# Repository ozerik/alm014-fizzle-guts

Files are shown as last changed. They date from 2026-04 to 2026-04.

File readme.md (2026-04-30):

# M4TM FZilter

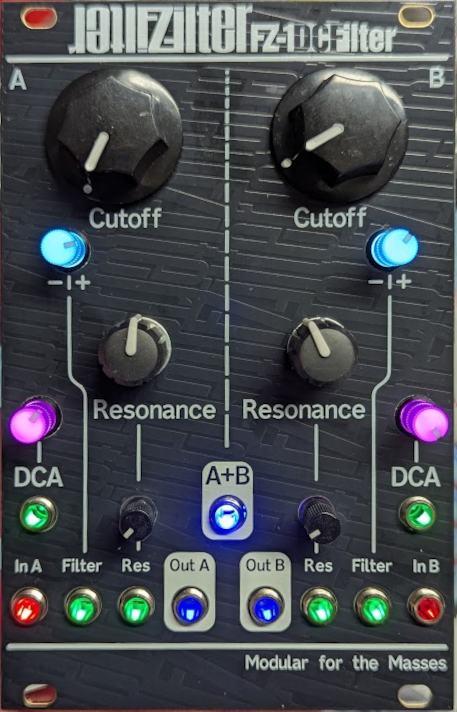
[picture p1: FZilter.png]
picture of my FZilter module


## Introduction

Here's my take on the excellent Fizzle Guts module by ALM/BusyCircuits. It rules.

I've redrawn the schematic, altering a few resistor values and adding ground-reference resistors after the capacitors on the input sides 
(how did input bias not saturate those caps? Are we relying on DC leakage in electrolytics?), I added a 2nd 5V voltage regulator for the microcontroller, lifted the
ground on the microcontroller side, and OF COURSE I added LEDs everywhere, inclduing the ones under the clear-shafted potentiometers. I haven't compared the
character of my version against the original, so who knows if there's any improvement. Probably not, but hey, fun project!

Back in the '80s, Casio released the FV-1 keyboard with four of the MB87186 chips inside. And that's the only place you can get them. The FV-1 and the FV-1M keyboard.
If you have one of these kicking around with a broken logic board or keybed or output whatever, you do have four of these chips that are probably okay. One of the chips I
built up into a module looked pretty rough, water? stains and corroded bent pins, still worked.

For more information on the MB87186 (and from what much of the code
was based on) see http://www.buchty.net/casio/dcf.html

See, this is a dual DCF and DCA. "D" standing for digital, of course, so digitally-controlled filter and amp. ALM developed the code to turn voltages into digital signals, and figured out (based on excellent work linked above) how to get that datastream into the chip so it knows what to do with it. Great work, everybody, hats off.

## Building and flashing the firmware

The most frightning part of this project was getting the code onto the microprocessor. The flash.sh shell script will work with the correct hardware,
but I don't have a Macintosh computer, or a USBTiny programmer. I just have a HP laptop and a bunch of Arduinos flashed with the "Arduino-as-ISP" firmware because I keep
losing them and making new ones. AND I'm not super comofortable with avrdude... so I'll include the .hex file over in the firmware folder and a bit of explanation of the
commands. It may be possible to brick the ATMega644 processor by setting fuses, at least something like that may have happened with one of mine.

> To use the original shell script...
>
> You'll need a basic 'usbtiny' AVR programmer.
>
> You'll need to install avr-gcc and avrdude.
>  
>   /(On mac using brew..)/
>   #+BEGIN_SRC
>   brew tap osx-cross/avr
>   brew install avr-gcc
>   brew install avrdude
>
>   #+END_SRC
>  Type 'make' in the firmare/ directory to compile the source code and
>
> then run './flash.sh' (with your programmer connected) to program the Fizzle.

Okay so here's what worked for me:

I followed the *arduous* steps over [here, which goes through how to create an AVR toolchain](https://tinusaur.com/guides/avr-gcc-toolchain/) and that
was complicated and weird, and the script in `flash.sh` wouldn't work. Mostly because avrdude changed the nanme of programmers, and who knows what else. Anyway,
as of April 2026, here's the command line I used to flash the ATMega644p chip:

`avrdude -V -p atmega644p -c avrisp -P COM5 -b 19200 -F -e -U hfuse:w:0xD8:m -U lfuse:w:0xFF:m -U efuse:w:0x04:m -U flash:w:"PATH TO fz1.hex FILE":a`

`-p atmega644p` means you're programming this particular chip

`-c avrisp` means you're using an Arduion-as-ISP programmer, which are [easy to build](https://docs.arduino.cc/built-in-examples/arduino-isp/ArduinoISP/) with an Arduino Nano

`-P COM5` referrs to which port you're using. Figure this out by looking at your Device Manager, under Ports (COM & LPT) and find the USB-SERIAL CH340 one (at least that's
what it'll be if you're using a cheap Nano clone)

`-b 19200` sets the BAUD rate, probably fine, don't even need it?

The `hfuse` and whatnot, those are fuses that tell the microprocessor which clock to use. The ATMega644 can clock itself, but for this project it must be clocked from the external 20MHz crystal. This might be how I bricked one of my modules, by trying to set fuses and messing an important one up.

The last important part of that command line is what file to flash. You'll find an fz1.hex file elsewhere in this repo, so download it somewhere and delete "PATH TO fz1.hex FILE" and replace it with "C:/Users/NicCage/Downloads/fz1.hex" (what's up Nic? cool movies) or whatever.

Then, plug your Arduino-as-ISP thingie into the header on the module, minding that you get the pins right, plug the Arduino into 
a USB port, open a command prompt window (bash shell if you've been following directions), paste that code into the command line, hit enter, and say "no" when it asks you if you want to re-set the fuse that was just set. Somebody smarter than me can fix whatever's causing that error.

SO anyway, this procedure worked for me, and I've got a functioning FZilter module in my possession.

## License

Code: MIT license.

Hardware: cc-by-sa-3.0

## Guidelines for derivative works

*ALM is a registered trademark.*

The name "ALM" should not be used on any of the derivative works you create from these files.

We kindly ask to do not name any derivatives 'FIZZLE GUTS' but give it a new name.

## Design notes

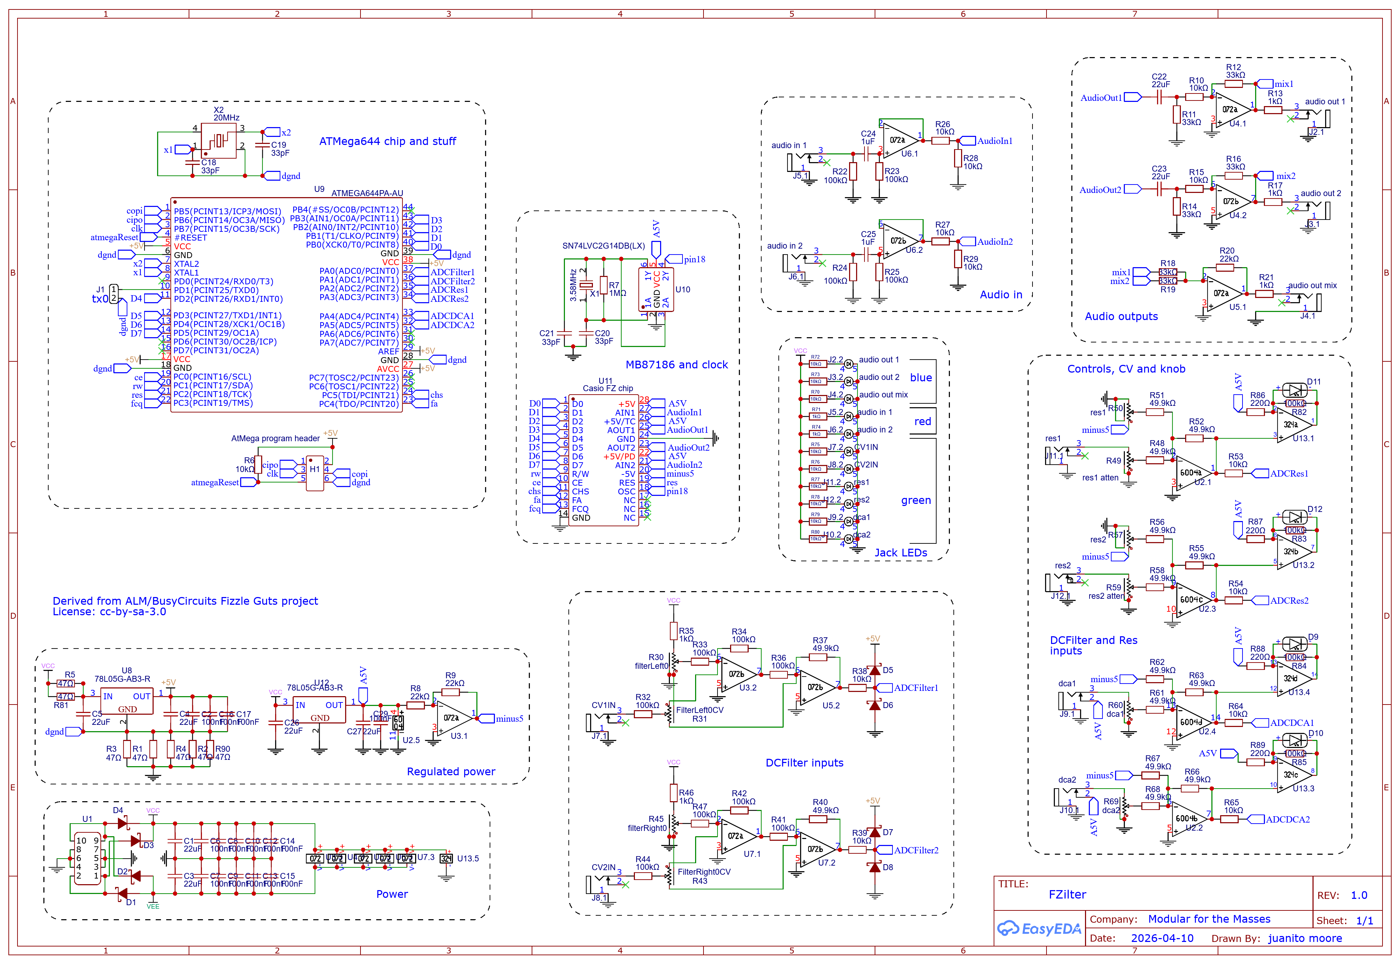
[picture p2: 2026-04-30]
hardware/M4TM_Schematics/FZilter_schematic.png

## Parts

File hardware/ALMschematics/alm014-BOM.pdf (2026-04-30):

### FZ-FILTER-REV003 Passives + IC’s BOM

Qty | Parts | Value | Device | Package | Description | MF
1 | R38 | 1M | RESISTOR0603 | R0603
14 | R1, R3, R7, R10, R12, R14, R22, R32, R33, R34, R36, R46, R9, R16 | 100K | RESISTOR0603 | R0603
15 | R15, R17, R18, R19, R20, R23, R25, R27, R30, R35, R53, R39, R11, R29, R31 | 49.9k | RESISTOR0603 | R0603
4 | R6, R48, R50, R51 | 33K | RESISTOR0603 | R0603
12 | R2, R4, R5, R21, R28, R42, R45, R47, R40, R41, R43, R44 | 10K | RESISTOR0603 | R0603
3 | R8, R13, R49 | 1K | RESISTOR0603 | R0603
2 | R26, R37 | 2.2K | RESISTOR0603 | R0603
13 | C3, C7, C8, C13, C14, C15, C17, C18, C22, C28, C29, C31, C41 | 100n | CAPACITOR0603 | C0603
4 | C11, C16, C23, C24 | 10n | CAPACITOR0603 | C0603
2 | C21, C9 | 1n | CAPACITOR0603 | C0603
2 | C6, C27 | 47pf | CAPACITOR0603 | C0603
2 | C19, C20 | 20pf | CAPACITOR0603 | C0603
5 | C1, C2, C5, C12, C26 | 10uf / 25V | CPOL-EUB | PANASONIC_B | POLARIZED CAPACITOR, European symbol | Panasonic EEEHA1E100WR (or equiv)
2 | C4, C25 | 1uf / 25V | CPOL-EUB | PANASONIC_B | POLARIZED CAPACITOR, European symbol | Panasonic EEE1HA010SR (or equiv)
2 | D3, D13 | BAT54S | BAT54S | SOT23 | Schottky Diodes | BAT45S
2 | D1, D2 | RS 301-906 | DIODESMB | SMB-DIODE | Diode | Vishay VS-MBRS130LTRPBF (or similar)
1 | QF1 | 3.58Mhz | | | 3.58Mhz Resonator | Murata CSTLS3M58G56-B0
5 | IC1, IC2, IC5, IC7, IC8 | TL072D | TL072D | SO08 | OP AMP | TL072
1 | IC3 | MCP6004 | MCP6004 | SO14 | OP AMP | MCP6004
1 | IC6 | ATMEGA644A | ATMEGA644A | TQFP44 | MCU | Mouser 556-ATMEGA644A-AU
1 | U1 | SN74LVC2G14DBV | SN74LVC2G14DBV | SOT23-6 | DUAL SCHMITT-TRIGGER INVERTER | Mouser 595-SN74LVC2G14DBVR
1 | U3 | 7805 | VREG-7805-DPAK2 | VREG-7805-DPAK2 | | Mouser L7805CD2T-TR
1 | Y2 | 8M10AHC49T | 8M10AHC49T | HC49U | 20Mhz Crystal | Mouser 420-200-20-5PX

All caps at least 16v. All resistors 1% at least 0.1 watt

1

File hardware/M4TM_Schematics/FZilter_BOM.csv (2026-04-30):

ID | Name | Designator | Footprint | Quantity | Manufacturer Part | Manufacturer | Supplier | Supplier Part
1 | 22uF | C1,C3,C4,C5,C22,C23,C26,C27 | C0805 | 8 | CL21A226MAQNNNE | SAMSUNG(三星) | LCSC | C45783
2 | 100nF | C2,C6,C7,C8,C9,C10,C11,C12,C13,C14,C15,C16,C17,C29 | C0603 | 14 | CC0603KRX7R9BB104 | YAGEO(国巨) | LCSC | C14663
3 | 33pF | C18,C19,C20,C21 | C0402 | 4 | 0402CG330J500NT | FH(风华) | LCSC | C1562
4 | 1uF | C24,C25 | C0805 | 2 | CL21B105KBFNNNE | SAMSUNG(三星) | LCSC | C28323
5 | B5819W_C8598 | D1,D2,D3,D4,D5,D6,D7,D8 | SOD-123_L2.7-W1.6-LS3.7-RD-1 | 8 | B5819W | CJ | LCSC | C8598
6 | 1x2_2.54mm_pin_header_Juanito | J1 | HDR-M-2.54_1X2 JUANITO | 1
7 | 47Ω | R1,R2,R3,R4,R5,R81,R90 | R0603 | 7 | 0603WAF470JT5E | UNI-ROYAL(厚声) | LCSC | C23182
8 | 10kΩ | R6,R10,R15,R26,R27,R28,R29,R38,R39,R53,R54,R64,R65,R70,R72,R73,R75,R76,R77,R78,R79,R80 | R0603 | 22 | 0603WAF1002T5E | UNI-ROYAL(厚声) | LCSC | C25804
9 | 1MΩ | R7 | R0603 | 1 | 0603WAF1004T5E | UNI-ROYAL(厚声) | LCSC | C22935
10 | 22kΩ | R8,R9,R20 | R0603 | 3 | 0603WAF2202T5E | UNI-ROYAL(厚声) | LCSC | C31850
11 | 33kΩ | R11,R12,R14,R16,R18,R19 | R0603 | 6 | 0603WAF3302T5E | UNI-ROYAL(厚声) | LCSC | C4216
12 | 1kΩ | R13,R17,R21,R35,R46,R71,R74 | R0603 | 7 | 0603WAF1001T5E | UNI-ROYAL(厚声) | LCSC | C21190
13 | 100kΩ | R22,R23,R24,R25,R32,R33,R34,R36,R41,R42,R44,R47,R82,R83,R84,R85 | R0603 | 16 | 0603WAF1003T5E | UNI-ROYAL(厚声) | LCSC | C25803
14 | 49.9kΩ | R37,R40,R48,R51,R52,R55,R56,R58,R61,R62,R63,R66,R67,R68 | R0603 | 14 | 0603WAF4992T5E | UNI-ROYAL(厚声) | LCSC | C23184
15 | 220Ω | R86,R87,R88,R89 | R0603 | 4 | 0603WAF2200T5E | UNI-ROYAL(厚声) | LCSC | C22962
16 | 78L05G-AB3-R | U8,U12 | SOT-89-3_L4.5-W2.5-P1.50-LS4.2-BR | 2 | 78L05G-AB3-R | UTC(友顺) | LCSC | C71136
17 | ATMEGA644PA-AU | U9 | TQFP-44_L10.0-W10.0-P0.80-LS12.0-BL | 1 | ATMEGA644PA-AU | MICROCHIP(美国微芯) | LCSC | C38349
18 | SN74LVC2G14DB(LX) | U10 | SOT-23-6_L2.9-W1.6-P0.95-LS2.9-BL | 1 | SN74LVC2G14DB(LX) | LX(灵星芯微) | LCSC | C22469937
19 | 3.58MHz | X1 | HC-49S_L11.4-W4.8-LS13.0 | 1 | SWXJHBCVH0-3.580000 | Starwave(思大) | LCSC | C22464956
20 | 20MHz | X2 | CRYSTAL-SMD_4P-L3.2-W2.5-BL | 1 | TAXM20M4RHBDDT2T | YJX(雅晶鑫) | LCSC | C2880033
21 | 6004 jm | U2 | TSSOP-14PLUS3D | 1 | TPMCP6004T-E/ST | TECH PUBLIC | LCSC | C42370557
22 | TL072CDT JUANITO | U3,U4,U5,U6,U7 | SOIC-8_L5.0-W4.0-P1.27-LS6.0-BL | 5 | TL072CDT | STMicroelectronics | LCSC | C6961
23 | LM324 Juanito 0 | U13 | SOIC-14_L8.7-W3.9-P1.27-LS6.0-TL | 1 | LM324DT | ST(意法半导体) | LCSC | C71035

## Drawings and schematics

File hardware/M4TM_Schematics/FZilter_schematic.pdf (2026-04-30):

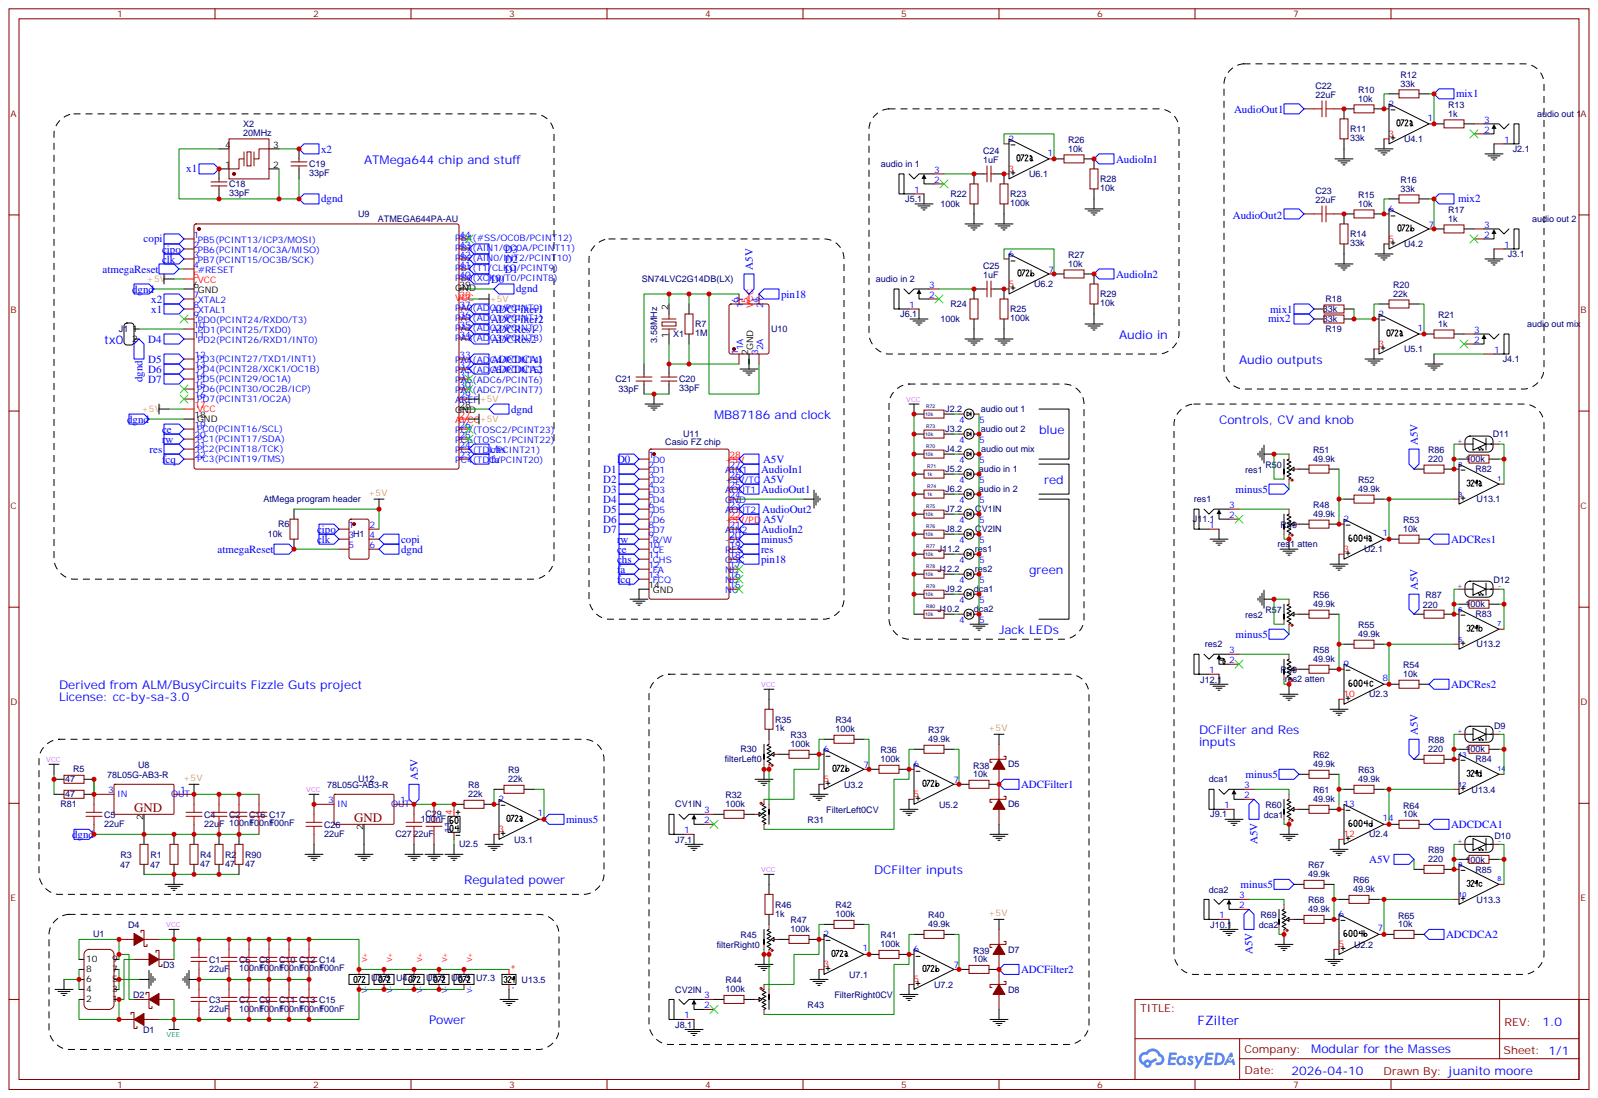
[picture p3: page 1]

mix1
mix2
Company: Modular for the Masses A⁵V A⁵V A⁵V

Controls, CV and knob

Derived from ALM/BusyCircuits Fizzle Guts project
License: cc-by-sa-3.0

Drawn By: juanito moore

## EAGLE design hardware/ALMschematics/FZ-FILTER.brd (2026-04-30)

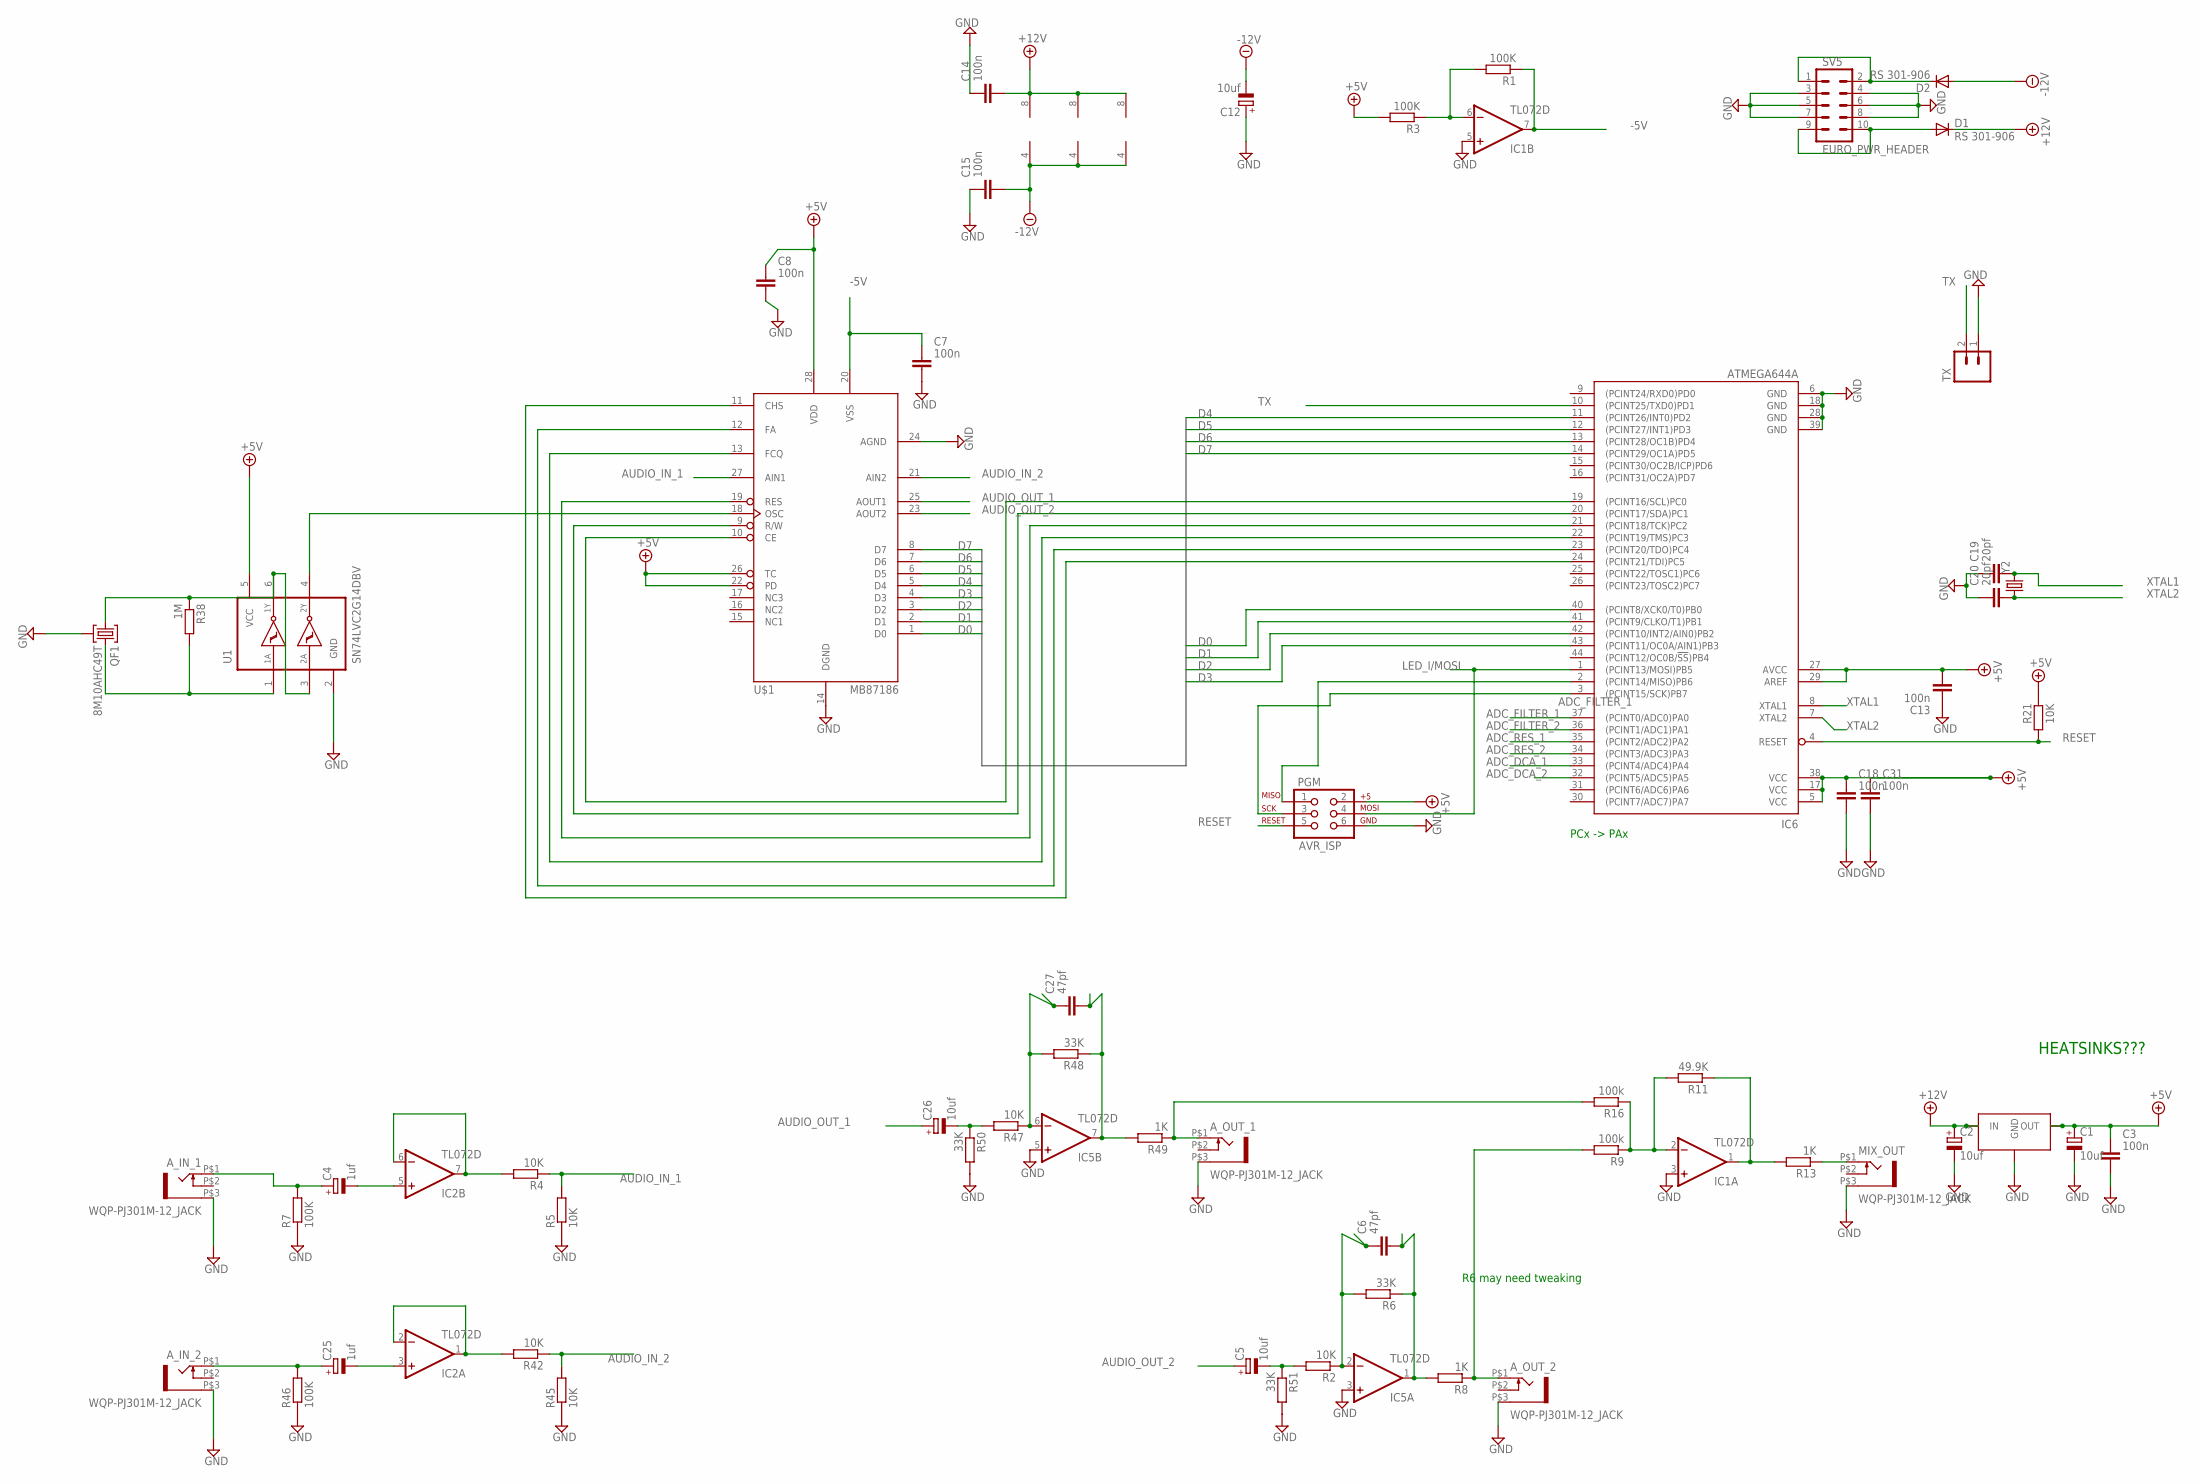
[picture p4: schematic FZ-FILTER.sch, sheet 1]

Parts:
A_IN_1, A_IN_2: WQP-PJ301M-12_JACK
A_OUT_1, A_OUT_2: WQP-PJ301M-12_JACK
C1, C2, C5, C12, C26: 10uf; PANASONIC_B
C3, C7, C8, C13, C14, C15, C18, C31: 100n; C0603
C4, C25: 1uf; PANASONIC_B
C6, C27: 47pf; C0603
C19, C20: 20pf; C0603
D1, D2: RS 301-906; SMB-DIODE
IC1, IC2, IC5: TL072D; SO08
IC6: ATMEGA644A; TQFP44
MIX_OUT: WQP-PJ301M-12_JACK
PGM: AVR_ISP; 2X3
QF1: 8M10AHC49T; HC49U
R1, R3, R7, R46: 100K; R0603
R2, R4, R5, R21, R42, R45, R47: 10K; R0603
R6, R48, R50, R51: 33K; R0603
R8, R13, R49: 1K; R0603
R9, R16: 100k; R0603
R11: 49.9K; R0603
R38: 1M; R0603
SV5: EURO_PWR_HEADER
TX: M02PTH; 1X02
U1: SN74LVC2G14DBV; SOT23-6
U3: 7805; VREG-7805-DPAK2
U$1: MB87186; DIP28
Y2: CRYSTALSMD; HC49UP

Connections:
+5V: C1.+, C3.1, C8.1, C13.2, C18.1, C31.1, IC6.5 (VCC), IC6.17 (VCC), IC6.27 (AVCC), IC6.29 (AREF), IC6.38 (VCC), PGM.2, R3.2, R21.2, U1.5 (VCC), U3.VOUT (OUT), U$1.22 (PD), U$1.26 (TC), U$1.28 (VDD); also elsewhere on the board
+12V: C2.+, C14.2, D1.C, IC1.8 (V+), IC2.8 (V+), IC5.8 (V+), U3.VIN (IN); also elsewhere on the board
-5V: C7.1, IC1.7 (OUT), R1.1, U$1.20 (VSS); also elsewhere on the board
-12V: C12.-, C15.2, D2.A, IC1.4 (V-), IC2.4 (V-), IC5.4 (V-); also elsewhere on the board
ADC_DCA_1: IC6.33 ((PCINT4/ADC4)PA4); also elsewhere on the board
ADC_DCA_2: IC6.32 ((PCINT5/ADC5)PA5); also elsewhere on the board
ADC_FILTER_1: IC6.37 ((PCINT0/ADC0)PA0); also elsewhere on the board
ADC_FILTER_2: IC6.36 ((PCINT1/ADC1)PA1); also elsewhere on the board
ADC_MISO: IC6.2 ((PCINT14/MISO)PB6), PGM.1
ADC_RES_1: IC6.35 ((PCINT2/ADC2)PA2); also elsewhere on the board
ADC_RES_2: IC6.34 ((PCINT3/ADC3)PA3); also elsewhere on the board
ADC_SCK: IC6.3 ((PCINT15/SCK)PB7), PGM.3
AUDIO_IN_1: R4.1, R5.2, U$1.27 (AIN1)
AUDIO_IN_2: R42.1, R45.2, U$1.21 (AIN2)
AUDIO_OUT_1: C26.+, U$1.25 (AOUT1)
AUDIO_OUT_2: C5.+, U$1.23 (AOUT2)
D0: IC6.40 ((PCINT8/XCK0/T0)PB0), U$1.1 (D0)
D1: IC6.41 ((PCINT9/CLKO/T1)PB1), U$1.2 (D1)
D2: IC6.42 ((PCINT10/INT2/AIN0)PB2), U$1.3 (D2)
D3: IC6.43 ((PCINT11/OC0A/AIN1)PB3), U$1.4 (D3)
D4: IC6.11 ((PCINT26/INT0)PD2), U$1.5 (D4)
D5: IC6.12 ((PCINT27/INT1)PD3), U$1.6 (D5)
D6: IC6.13 ((PCINT28/OC1B)PD4), U$1.7 (D6)
D7: IC6.14 ((PCINT29/OC1A)PD5), U$1.8 (D7)
GND: A_IN_1.P$3 (1), A_IN_2.P$3 (1), A_OUT_1.P$3 (1), A_OUT_2.P$3 (1), C1.-, C2.-, C3.2, C7.2, C8.2, C12.+, C13.1, C14.1, C15.1, C18.2, C19.1, C20.1, C31.2, IC1.3 (+IN), IC1.5 (+IN), IC5.3 (+IN), IC5.5 (+IN), IC6.6 (GND), IC6.18 (GND), IC6.28 (GND), IC6.39 (GND), MIX_OUT.P$3 (1), PGM.6, QF1.2, R5.1, R7.1, R45.1, R46.1, R50.2, R51.2, SV5.3, SV5.4, SV5.5, SV5.6, SV5.7, SV5.8, TX.1, U1.2 (GND), U3.GND, U$1.14 (DGND), U$1.24 (AGND); also elsewhere on the board
LED_I/MOSI: IC6.1 ((PCINT13/MOSI)PB5), PGM.4
unnamed: D2.C, SV5.1, SV5.2
unnamed: IC1.6 (-IN), R1.2, R3.1
unnamed: D1.A, SV5.9, SV5.10
unnamed: IC2.6 (-IN), IC2.7 (OUT), R4.2
unnamed: C6.1, IC5.2 (-IN), R2.1, R6.2
unnamed: C6.2, IC5.1 (OUT), R6.1, R8.2
unnamed: C5.-, R2.2, R51.1
unnamed: A_OUT_1.P$1 (2), R16.2, R49.1
unnamed: IC1.2 (-IN), R9.1, R11.2, R16.1
unnamed: IC1.1 (OUT), R11.1, R13.2
unnamed: A_OUT_2.P$1 (2), R8.1, R9.2
unnamed: C4.-, IC2.5 (+IN)
unnamed: A_IN_1.P$1 (2), C4.+, R7.2
unnamed: C25.-, IC2.3 (+IN)
unnamed: IC2.1 (OUT), IC2.2 (-IN), R42.2
unnamed: A_IN_2.P$1 (2), C25.+, R46.2
unnamed: C27.1, IC5.6 (-IN), R47.1, R48.2
unnamed: C27.2, IC5.7 (OUT), R48.1, R49.2
unnamed: C26.-, R47.2, R50.1
unnamed: MIX_OUT.P$1 (2), R13.1
unnamed: IC6.19 ((PCINT16/SCL)PC0), U$1.10 (CE)
unnamed: IC6.20 ((PCINT17/SDA)PC1), U$1.9 (R/W)
unnamed: IC6.21 ((PCINT18/TCK)PC2), U$1.19 (RES)
unnamed: IC6.22 ((PCINT19/TMS)PC3), U$1.13 (FCQ)
unnamed: IC6.23 ((PCINT20/TDO)PC4), U$1.12 (FA)
unnamed: IC6.24 ((PCINT21/TDI)PC5), U$1.11 (CHS)
unnamed: U1.4 (2Y), U$1.18 (OSC)
unnamed: QF1.1, R38.1, U1.3 (2A), U1.6 (1Y)
unnamed: QF1.3, R38.2, U1.1 (1A)
RESET: IC6.4 (RESET), PGM.5, R21.1
TX: IC6.10 ((PCINT25/TXD0)PD1), TX.2
XTAL1: C19.2, IC6.8 (XTAL1), Y2.2
XTAL2: C20.2, IC6.7 (XTAL2), Y2.1

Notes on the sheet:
PCx -> PAx
HEATSINKS???
R6 may need tweaking

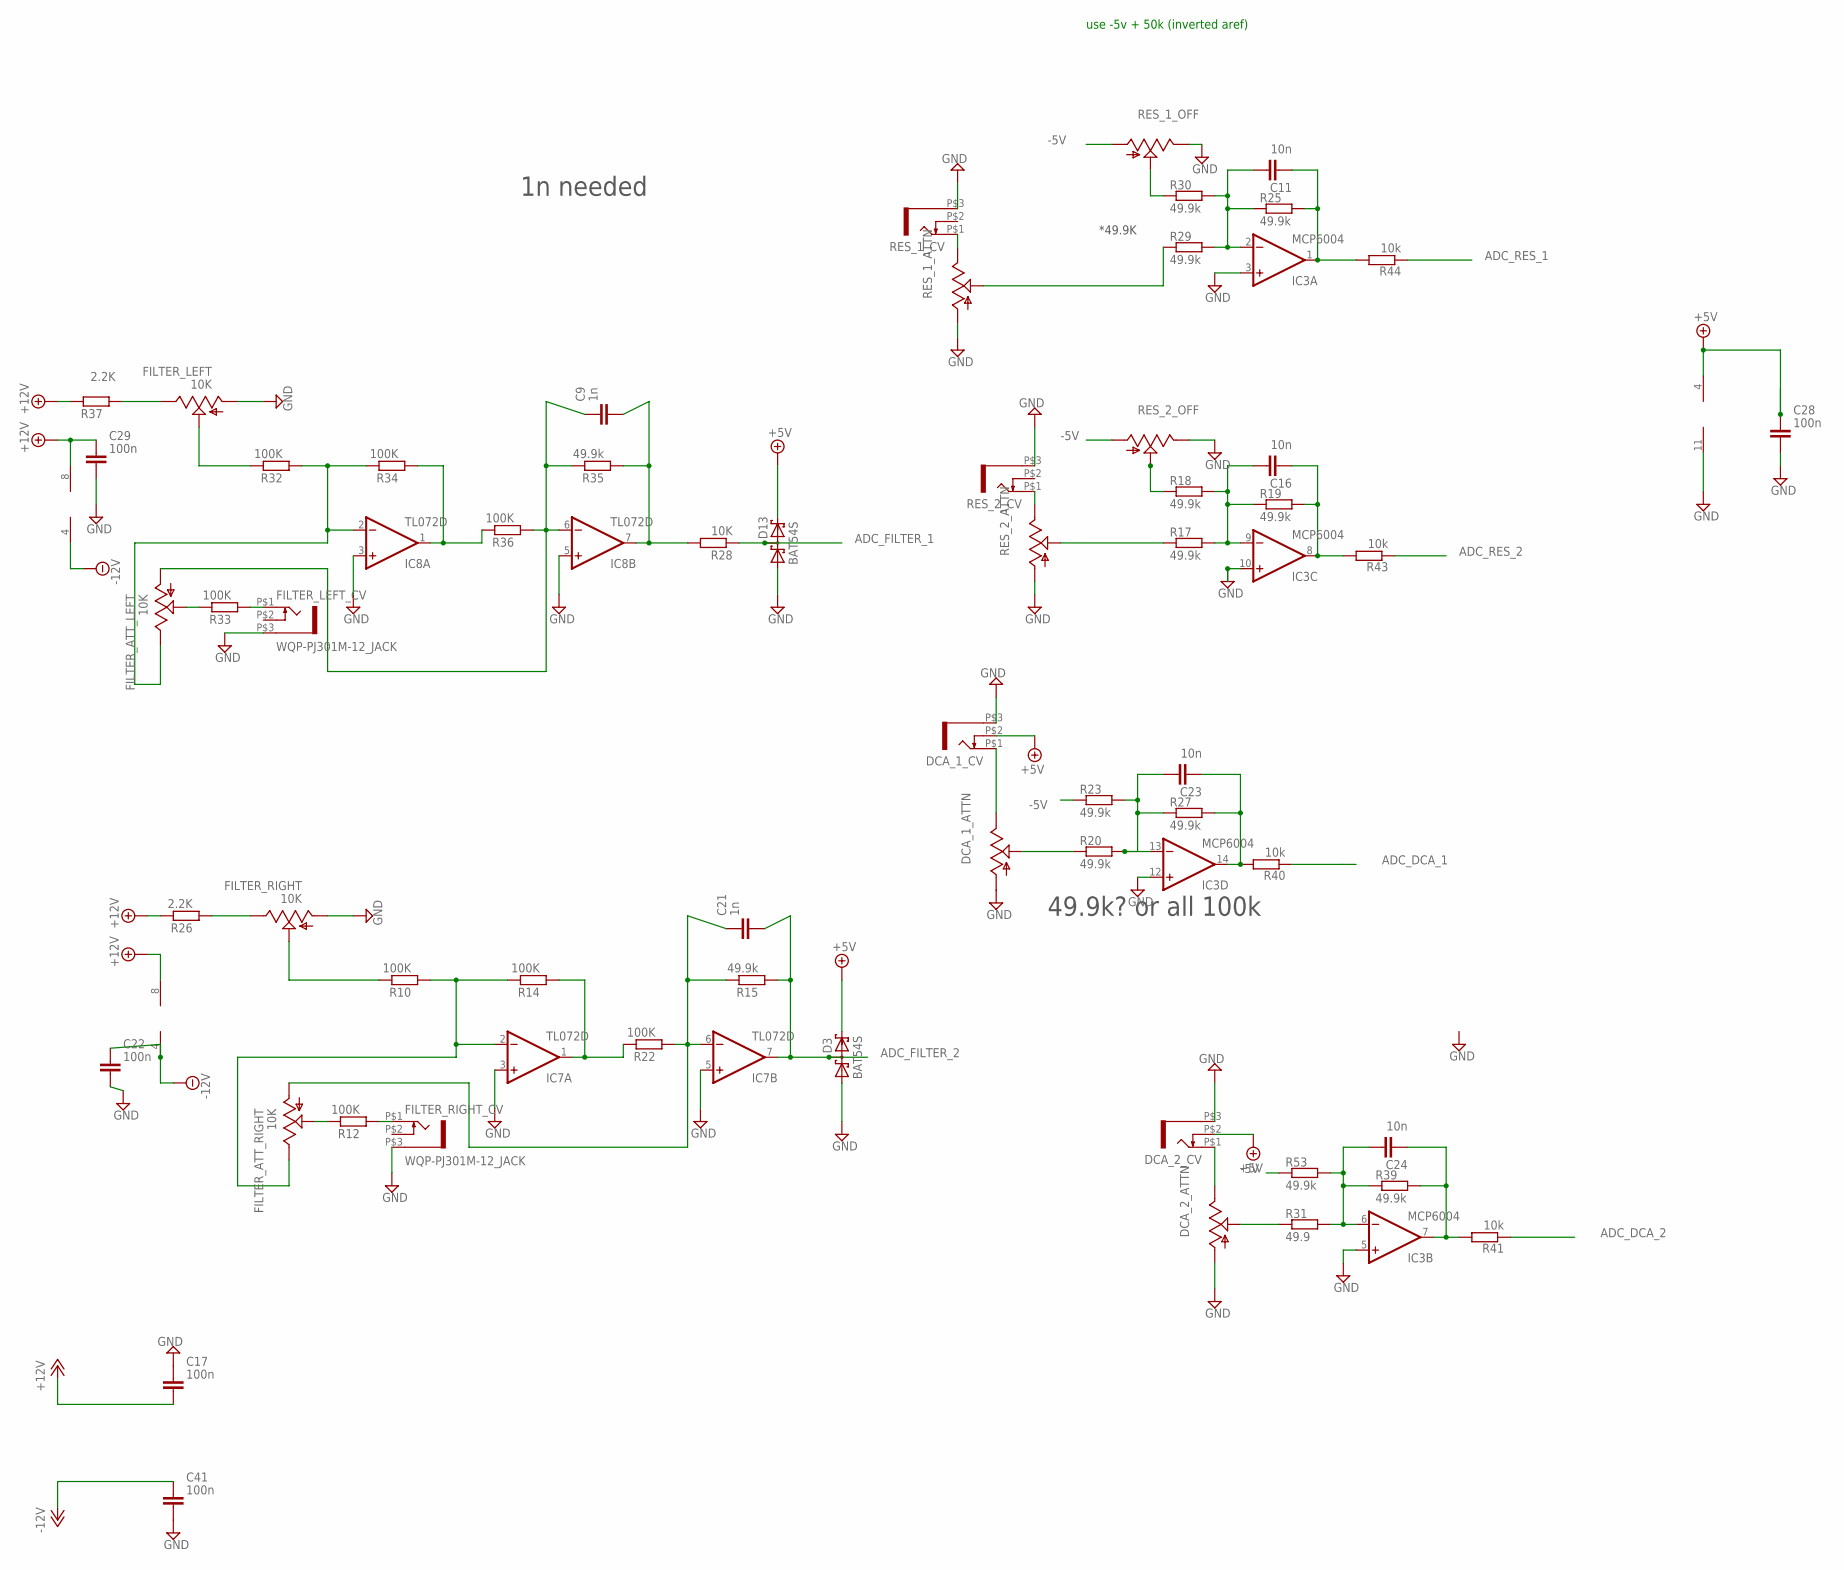
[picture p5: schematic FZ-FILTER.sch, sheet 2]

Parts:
C9, C21: 1n; C0603
C11, C16, C23, C24: 10n; C0603
C17, C22, C28, C29, C41: 100n; C0603
D3, D13: BAT54S; SOT23
DCA_1_ATTN, DCA_2_ATTN: ALPHA-9MMA; EVUF
DCA_1_CV, DCA_2_CV: WQP-PJ301M-12_JACK
FILTER_ATT_LEFT: 10K; EVUF
FILTER_ATT_RIGHT: 10K; EVUF
FILTER_LEFT: 10K; EVUF
FILTER_LEFT_CV: WQP-PJ301M-12_JACK
FILTER_RIGHT: 10K; EVUF
FILTER_RIGHT_CV: WQP-PJ301M-12_JACK
IC3: MCP6004; SO14
IC7, IC8: TL072D; SO08
R10, R12, R14, R22, R32, R33, R34, R36: 100K; R0603
R15, R17, R18, R19, R20, R23, R25, R27, R29, R30, R35, R39, R53: 49.9k; R0603
R26, R37: 2.2K; R0603
R28: 10K; R0603
R31: 49.9; R0603
R40, R41, R43, R44: 10k; R0603
RES_1_ATTN, RES_1_OFF, RES_2_ATTN, RES_2_OFF: ALPHA-9MMA; EVUF
RES_1_CV, RES_2_CV: WQP-PJ301M-12_JACK

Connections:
+5V: C28.1, D3.2 (C2), D13.2 (C2), DCA_1_CV.P$2 (3), DCA_2_CV.P$2 (3), IC3.4 (V+); also elsewhere on the board
+12V: C17.2, C29.1, IC7.8 (V+), IC8.8 (V+), R26.2, R37.2; also elsewhere on the board
-5V: R23.1, R53.1, RES_1_OFF.1 (A), RES_2_OFF.1 (A); also elsewhere on the board
-12V: C22.1, C41.1, IC7.4 (V-), IC8.4 (V-); also elsewhere on the board
ADC_DCA_1: R40.1; also elsewhere on the board
ADC_DCA_2: R41.1; also elsewhere on the board
ADC_FILTER_1: D13.3 (C1A2), R28.1; also elsewhere on the board
ADC_FILTER_2: C21.2, D3.3 (C1A2), IC7.7 (OUT), R15.1; also elsewhere on the board
ADC_RES_1: R44.1; also elsewhere on the board
ADC_RES_2: R43.1; also elsewhere on the board
GND: C17.1, C22.2, C28.2, C29.2, C41.2, D3.1 (A1), D13.1 (A1), DCA_1_ATTN.1 (A), DCA_1_CV.P$3 (1), DCA_2_ATTN.1 (A), DCA_2_CV.P$3 (1), FILTER_LEFT.1 (A), FILTER_LEFT_CV.P$3 (1), FILTER_RIGHT.1 (A), FILTER_RIGHT_CV.P$3 (1), IC3.3 (+IN), IC3.5 (+IN), IC3.10 (+IN), IC3.11 (V-), IC3.12 (+IN), IC7.3 (+IN), IC7.5 (+IN), IC8.3 (+IN), IC8.5 (+IN), RES_1_ATTN.1 (A), RES_1_CV.P$3 (1), RES_1_OFF.3 (E), RES_2_ATTN.1 (A), RES_2_CV.P$3 (1), RES_2_OFF.3 (E); also elsewhere on the board
I7: C9.2, IC8.7 (OUT), R28.2, R35.1
unnamed: RES_1_ATTN.3 (E), RES_1_CV.P$1 (2)
unnamed: R30.1, RES_1_OFF.2 (S)
unnamed: C24.1, IC3.6 (-IN), R31.2, R39.1, R53.2
unnamed: C11.2, IC3.1 (OUT), R25.2, R44.2
unnamed: R29.1, RES_1_ATTN.2 (S)
unnamed: DCA_1_ATTN.3 (E), DCA_1_CV.P$1 (2)
unnamed: C16.1, IC3.9 (-IN), R17.2, R18.2, R19.1
unnamed: R18.1, RES_2_OFF.2 (S)
unnamed: RES_2_ATTN.3 (E), RES_2_CV.P$1 (2)
unnamed: C23.1, IC3.13 (-IN), R20.2, R23.2, R27.1
unnamed: DCA_1_ATTN.2 (S), R20.1
unnamed: DCA_2_ATTN.2 (S), R31.1
unnamed: C16.2, IC3.8 (OUT), R19.2, R43.2
unnamed: DCA_2_ATTN.3 (E), DCA_2_CV.P$1 (2)
unnamed: FILTER_RIGHT.2 (S), R10.2
unnamed: FILTER_ATT_RIGHT.3 (E), IC7.2 (-IN), R10.1, R14.2
unnamed: C11.1, IC3.2 (-IN), R25.1, R29.2, R30.2
unnamed: FILTER_RIGHT_CV.P$1 (2), R12.1
unnamed: FILTER_ATT_RIGHT.2 (S), R12.2
unnamed: IC7.1 (OUT), R14.1, R22.2
unnamed: C21.1, FILTER_ATT_RIGHT.1 (A), IC7.6 (-IN), R15.2, R22.1
unnamed: FILTER_RIGHT.3 (E), R26.1
unnamed: FILTER_LEFT.2 (S), R32.2
unnamed: FILTER_ATT_LEFT.3 (E), IC8.2 (-IN), R32.1, R34.2
unnamed: FILTER_LEFT_CV.P$1 (2), R33.1
unnamed: IC8.1 (OUT), R34.1, R36.2
unnamed: C9.1, FILTER_ATT_LEFT.1 (A), IC8.6 (-IN), R35.2, R36.1
unnamed: FILTER_LEFT.3 (E), R37.1
unnamed: FILTER_ATT_LEFT.2 (S), R33.2
unnamed: R17.1, RES_2_ATTN.2 (S)
REL1_ADC: C23.2, IC3.14 (OUT), R27.2, R40.2
REL2_ADC: C24.2, IC3.7 (OUT), R39.2, R41.2

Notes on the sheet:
use -5v + 50k (inverted aref)
49.9k? or all 100k
1n needed
*49.9K

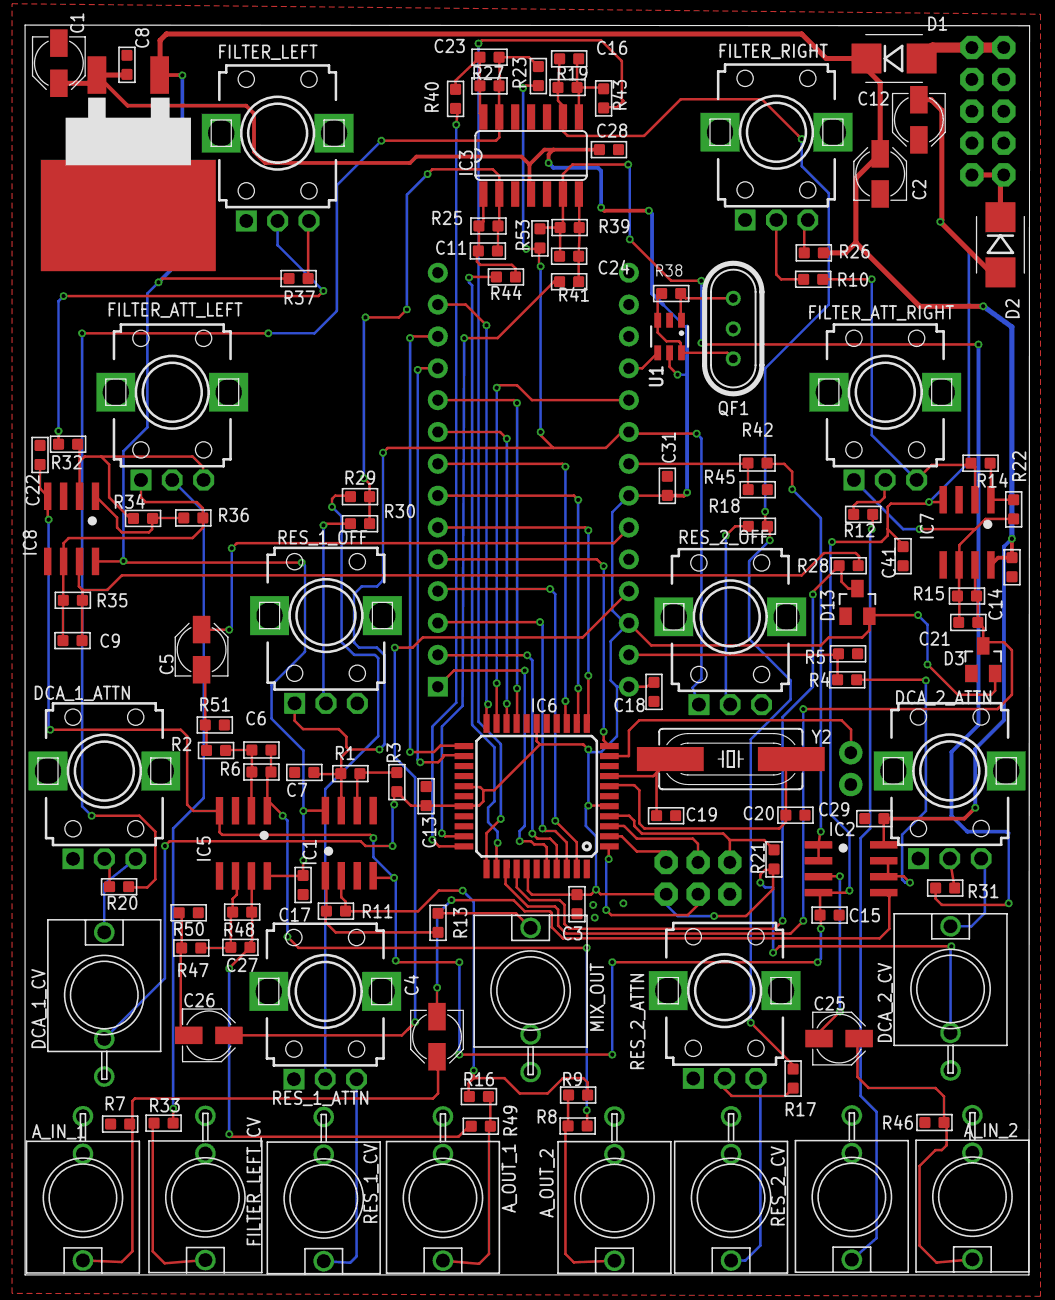
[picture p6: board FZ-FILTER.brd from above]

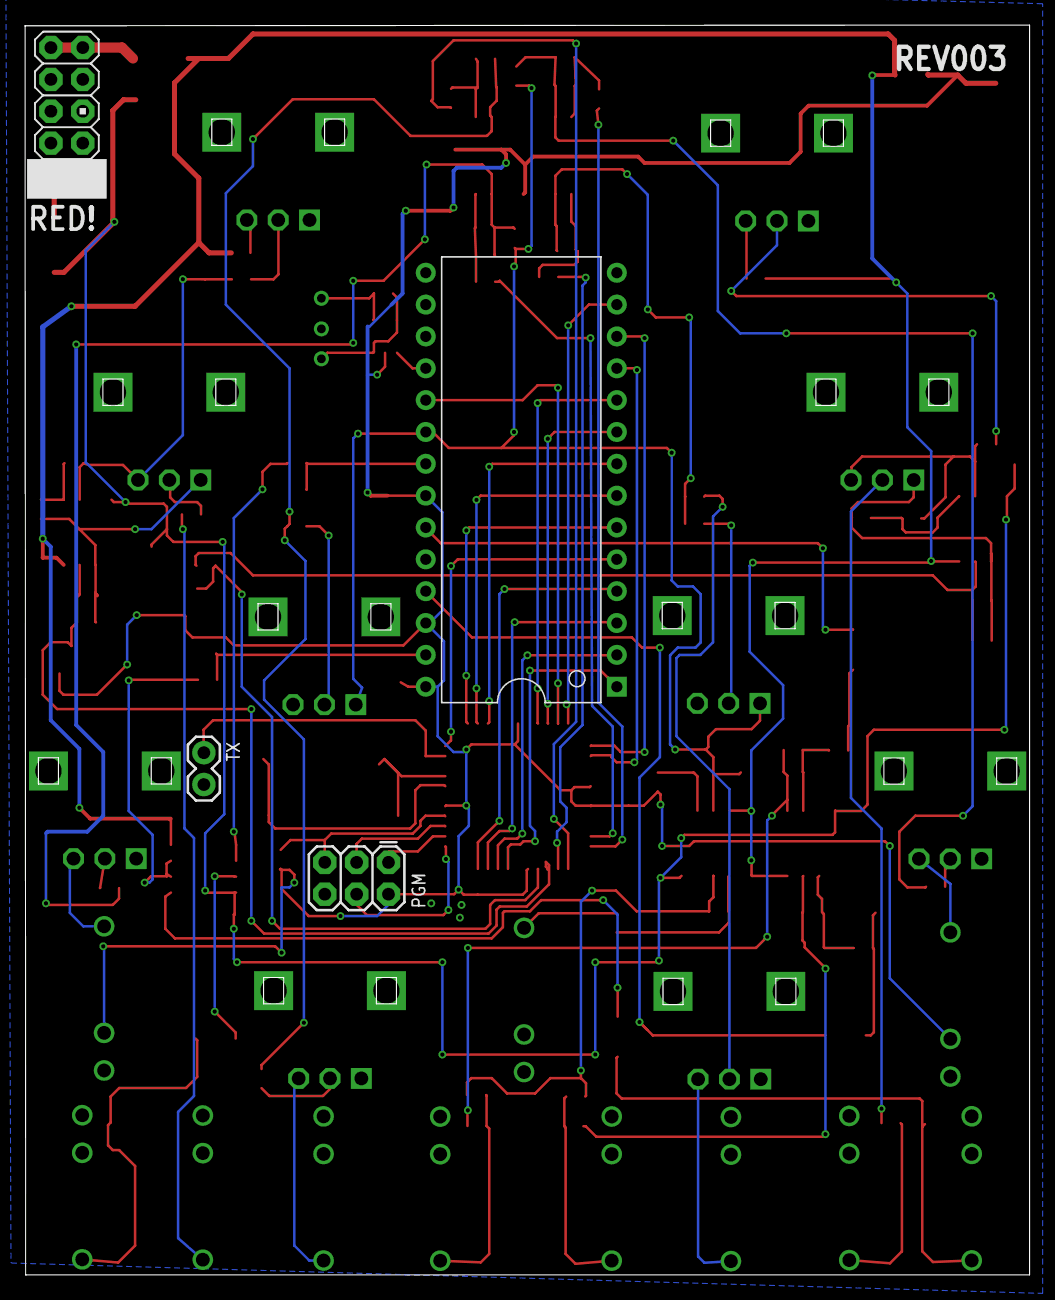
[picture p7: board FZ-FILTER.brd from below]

Board: 2 copper layers, 80.1 x 99.7 mm, 122 parts (5 on the bottom side), 92 nets.

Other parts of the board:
U$2: LOGO_WEEE

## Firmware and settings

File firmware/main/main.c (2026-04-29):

/*
*   ALM014 'FIZZLE GUTS' firmware 
*   
*   Copyright (c) 2014 ALM Co Ltd
*   
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
*/
#include "uu.h"
#include <avr/pgmspace.h>
#include <util/delay.h>


#define PIN_FZ_D0 PIN_B0
#define PIN_FZ_D1 PIN_B1
#define PIN_FZ_D2 PIN_B2
#define PIN_FZ_D3 PIN_B3
#define PIN_FZ_D4 PIN_D2
#define PIN_FZ_D5 PIN_D3
#define PIN_FZ_D6 PIN_D4
#define PIN_FZ_D7 PIN_D5

#define PIN_FZ_CHS PIN_C5
#define PIN_FZ_FA  PIN_C4
#define PIN_FZ_FCQ PIN_C3
#define PIN_FZ_RES PIN_C2
#define PIN_FZ_RW  PIN_C1
#define PIN_FZ_CE  PIN_C0

#define ADC_CHAN_FILTER_0 0
#define ADC_CHAN_FILTER_1 1
#define ADC_CHAN_RES_0 2
#define ADC_CHAN_RES_1 3
#define ADC_CHAN_DCA_0 4
#define ADC_CHAN_DCA_1 5


void cycle ();

int analog_read(uint8_t chan)
{
  uint8_t low, high;
  
  /* switch to ADMUX for (1<<6) - AVcc with external capacitor on AREF pin  */
  ADMUX = chan; // AREF, Internal Vref turned off  & chan 0 

  _delay_us(100); /* wait for mux to settle */
  
  ADCSRA = (1<<ADEN) | (1<<ADPS2) | (1<<ADPS1);
  /* Start conversion */
  ADCSRA |= (1<<ADSC);
  /* Wait.. */
  while (uu_bit_is_set(ADCSRA, ADSC));
  /* Collect */
  low  = ADCL;
  high = ADCH;

  return (high << 8) | low;
}

void FZ_poke (uint8_t data) 
{
  uu_pin_digital_write (PIN_FZ_RW, LOW); /* chip write enable */
  
  uu_pin_digital_write( PIN_FZ_D0, (data & 0x1));
  uu_pin_digital_write( PIN_FZ_D1, ((data>>1) & 0x1));
  uu_pin_digital_write( PIN_FZ_D2, ((data>>2) & 0x1));
  uu_pin_digital_write( PIN_FZ_D3, ((data>>3) & 0x1));
  uu_pin_digital_write( PIN_FZ_D4, ((data>>4) & 0x1));
  uu_pin_digital_write( PIN_FZ_D5, ((data>>5) & 0x1));
  uu_pin_digital_write( PIN_FZ_D6, ((data>>6) & 0x1));
  uu_pin_digital_write( PIN_FZ_D7, ((data>>7) & 0x1));

  _delay_us(10);

  uu_pin_digital_write (PIN_FZ_RW, HIGH); /* chip write disable */
}  


void setup () 
{
  int c, i = 0;

  uu_init(0);

  /* ADC's */
  uu_pin_mode( PIN_A0, INPUT);
  uu_pin_mode( PIN_A1, INPUT);
  uu_pin_mode( PIN_A2, INPUT);
  uu_pin_mode( PIN_A3, INPUT);
  uu_pin_mode( PIN_A4, INPUT);
  uu_pin_mode( PIN_A5, INPUT);
  
  uu_pin_mode( PIN_FZ_D0, OUTPUT);
  uu_pin_mode( PIN_FZ_D1, OUTPUT);
  uu_pin_mode( PIN_FZ_D2, OUTPUT);
  uu_pin_mode( PIN_FZ_D3, OUTPUT);
  uu_pin_mode( PIN_FZ_D4, OUTPUT);
  uu_pin_mode( PIN_FZ_D5, OUTPUT);
  uu_pin_mode( PIN_FZ_D6, OUTPUT);
  uu_pin_mode( PIN_FZ_D7, OUTPUT);
  
  uu_pin_mode( PIN_FZ_CHS, OUTPUT);
  uu_pin_mode( PIN_FZ_FA, OUTPUT);
  uu_pin_mode( PIN_FZ_FCQ, OUTPUT);
  uu_pin_mode( PIN_FZ_RES, OUTPUT);
  uu_pin_mode( PIN_FZ_RW, OUTPUT);
  uu_pin_mode( PIN_FZ_CE, OUTPUT);
  
  uu_pin_digital_write (PIN_FZ_CE, LOW); /* chip enable */

  uu_pin_digital_write (PIN_FZ_RW, HIGH); /* chip write disable */
  
  uu_pin_digital_write (PIN_FZ_RES, LOW); /* Reset - low active */
  uu_delay_ms(100);
  uu_pin_digital_write (PIN_FZ_RES, HIGH); /* Reset - low active */
  

  uu_pin_digital_write (PIN_FZ_CHS, HIGH); /* channel 0 - channel select */

  uu_pin_digital_write (PIN_FZ_FA, LOW); /* gain - 10 bit? */
  uu_pin_digital_write (PIN_FZ_FCQ, LOW); /* ??? */

  FZ_poke (0xff);  		/* Gain - all 8 bits */

  uu_pin_digital_write (PIN_FZ_FCQ, HIGH); /* gain */

  FZ_poke (0xff);  		/* Gain - just upper 2 bits */
  
}

void cycle () 
{
  static int prev_dca[2], prev_cutoff[2], prev_rez[2], hyst_dca[2], hyst_cutoff[2], hyst_rez[2];;

  int dca, cutoff = 0, rez = 0, i = 0;

  /* Note 6 over 4 as seems to be much more noise on ADC */
#define DO_HYST(c,p) if ( ((c) > (p) + 4) || ((c) < (p) - 4) ) { (p) = (c); } else { (c) = (p); }

  for (i=0; i<2; i++)
    {
      uu_pin_digital_write (PIN_FZ_CHS, !i); /* channel select */
     
      dca = 0x3ff - analog_read(ADC_CHAN_DCA_0+i);

      DO_HYST(dca, hyst_dca[i]);
  
      if (dca != prev_dca[i])
	{
	  uu_pin_digital_write (PIN_FZ_FA, LOW); /* gain - 10 bit? */
	  uu_pin_digital_write (PIN_FZ_FCQ, HIGH); /* gain */

	  /* 3 for high gain not to zero*/
	  /* 1 for for low gain */
	  
	  FZ_poke (dca >> 8);  		/* Gain - just upper 2 bits - do first*/
	  uu_pin_digital_write (PIN_FZ_FA, LOW); /* gain - 10 bit? */
	  uu_pin_digital_write (PIN_FZ_FCQ, LOW); /* ??? */
	  FZ_poke (dca & 0xff);
      
	  prev_dca[i] = dca;
	}

      //rez = 0xf - (analog_read(ADC_CHAN_RES_0) >> 6); /* 4 bit? */
      rez = (0x3ff - (analog_read(ADC_CHAN_RES_0+i))); /* 4 bit? */

      DO_HYST(rez, hyst_rez[i]);
      
      if (rez != prev_rez[i])
	{
	  uu_pin_digital_write (PIN_FZ_FA, HIGH); /* High DCF control */
	  uu_pin_digital_write (PIN_FZ_FCQ, LOW); /* ??? */

	  FZ_poke (rez >> 6);  		/* resonance - MSB? just 4 bits */
	  
	  prev_rez[i] = rez;
	}

      cutoff = analog_read(ADC_CHAN_FILTER_0+i); /* 7 bit? */

      DO_HYST(cutoff, hyst_cutoff[i]);
      
      if (cutoff != prev_cutoff[i])
	{
	  uu_pin_digital_write (PIN_FZ_FA, HIGH);
	  uu_pin_digital_write (PIN_FZ_FCQ, HIGH);

	  FZ_poke (cutoff >> 3);  		/* filter cut off ? */

	  prev_cutoff[i] = cutoff;
	}
    }

}


int main(void)
{
  setup();
  while (TRUE)
    cycle();
}

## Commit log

2026-04-29 Created the FZIlter branch of project
    New PCB design,
    [FZ-FILTER.kicad_sch, FZ-FILTER_1.kicad_sch, FZ-FILTER_2.kicad_sch]
2026-04-30 Added all my work
    [FZ-FILTER.brd, FZ-FILTER.sch, FZilter_BOM.csv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]
2026-04-30 Removed some silkscreen

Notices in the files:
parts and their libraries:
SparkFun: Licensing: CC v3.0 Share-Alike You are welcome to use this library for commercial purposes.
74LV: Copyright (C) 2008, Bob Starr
